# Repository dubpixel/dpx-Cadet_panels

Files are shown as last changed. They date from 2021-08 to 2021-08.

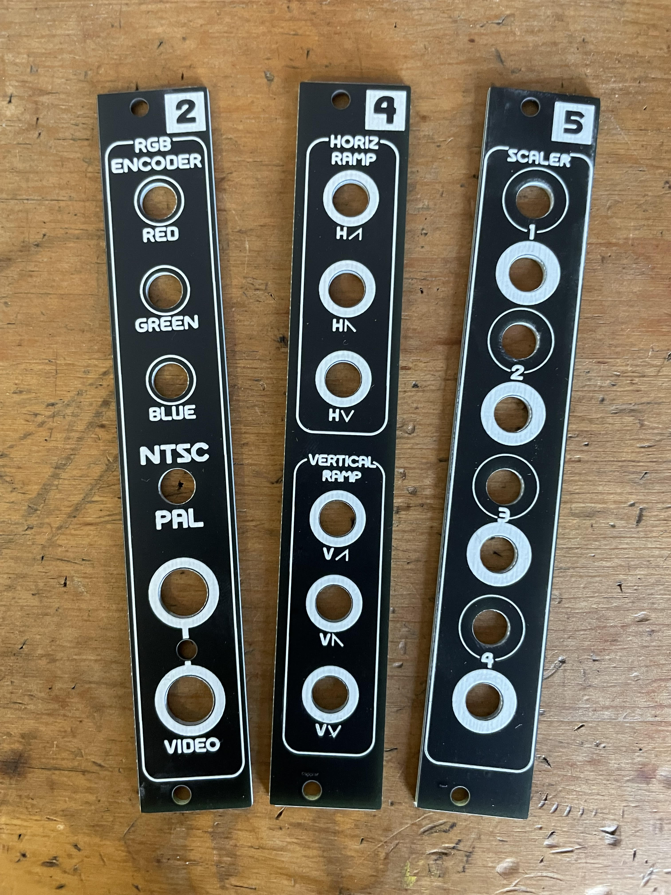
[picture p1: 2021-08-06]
photos/PANELS_1.jpg

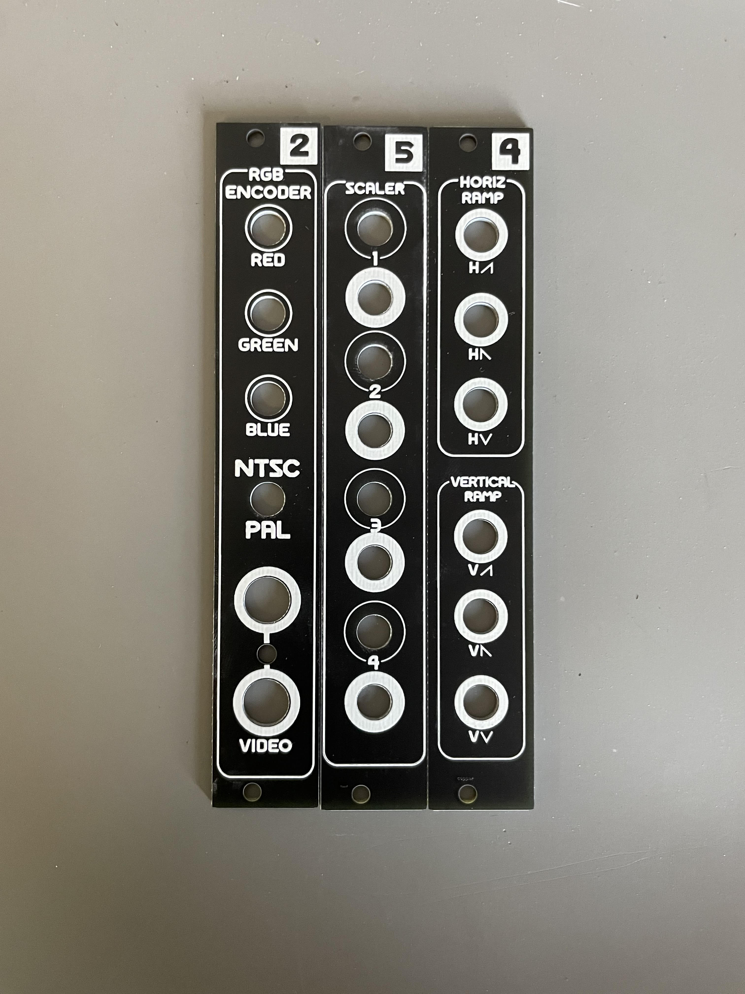
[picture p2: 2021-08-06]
photos/PANELS_5.jpg

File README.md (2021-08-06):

# dpx-Cadet_panels
**dubpixel** made panels for the LZX-cadet series of video synth modules.

most recently LZX cleared out their backstock of some old boards.
being in the middle of working on a euro-Vidiot panel, I used this as another exercise in panel making with a quicker time to live on checking if my process worked.

art-wise...
the style is trying to be a bit cadet-ish but im not the biggest fan of the art that i made - it was more about getting the holes right :)

there are here:
ai, dxf, fusion,360 eagle, and gerber files.
if you need some other intermediate perhaps i can provide. email below.

**//STATUS as of 8.4.21://**

- any place PJ302M is used I have used MJ-3536N as that is only part in stock i had to check spacing. 
- the diameter of the CUI part (MJ) is larger, and thusly the PJ302M fits with room to spare..maybe too much room (slop) but i only have 1 PJ to test with versus 12 MJ.

**CADET II  - RGB Encoder** :// looks very close -  if not 100% - did not have the lowermounting hardwarwe to confirm that it is in the right spot

**CADET IV - RAMPS** :// (revised) fits, looks good. I dont know why when i assembled before i didnt feel it was right. #needscoffee

**CADET V - SCALER** :// fits, looks good. might be an issue with the gerber in the silkscreen but also may be MFG. 

**//STATUS as of 8.2.21://**

**CADET II  - RGB Encoder** :// looks very close -  if not 100% - did not have the lowermounting hardwarwe to confirm that it is in the right spot

**CADET IV - RAMPS** :// NFG - needs bottom 3 holes to be adjusted. not sure what happened. PEBCAC (problem exists between caliper and chair)

**CADET V - SCALER** :// fits, looks good. might be an issue with the gerber in the silkscreen but also may be MFG. 

**if you arent up for mucking about and just wanna hit "PRINT" - **

go to gerbers-->fromFusion--> ...those are the files i printed formatted for JLCPCB, sorted accoding to status. made in fusion electronics (BLEGH!)

the files in fromEagle are theoretically identical from a physical perspective but may have minor variations in artwork as FE and eagle handle the dxf import in slightly different ways.
im not a fan of Autodesk ansclussing eagle into fusion.
but at least the poly import and text art workflow is getting speedier.

****process for creating these was roughly as follows****

==>draw 2d sketch in Fusion using parametric dimensions for edge spacing, board size, hole spacing etc.
- link all holes of same size to one hole.
- exit sketch, save, extrude 2mm
- create 3d PCB from sketch profile
- create fusion360 electronics project file.
- create a dummy schematic in that file
- create a 2d board link & it to the schemaitc
- link the 3d board to the 2d board

==>now you should have a board outline in fusion electronics on layer 20.  
- you can link this now to eagle if you want and continue the steps there, but the dxf import sadly works better in fusion electronics than eagle.
- plus also the polys move faster...renders cleaner. 
- RIP EAGLE... sad sad sad... George swears theyre not EOL'ing it but I dont beleive him. 
- so sorry if i say eagle anywhere and actually mean 'fusion electronics' blegghhh..

==>i now start work with the addhole.ulp
- use run 'addhole.ulp --install' to install the contextural menu
- then u can now click each hole outline and have it replace with the right drill hole. p neato
- back in fusion, now export your sketch to dxf
- import the DXF into AI onto a layer and lock it - this is your board outline and hole reference

==>now, make art in AI  on a new layer on top of the guide layer
- be sure to trace outlines of text, stroke with .1 mm line or smaller
- be sure to cut things with holes in them in half (like the letter O  - or even P...). knife/scissors tool
- add lots of points for paths  - not too many - but more points is better for maintaining curves once inside eagle. there is a balance between not choking eagle
- DELETE the guide lahyer (not turn off) - xcept for one point of registration... like a mounting screw hole
- export DXF in 2013 format. 

==>NOW - import into eagle or fusion electronics (actually imports less broken into fusion elec).
 - eagle is slower on the vector import and seems to want more points to not break P's o's and other 'cored' shapes/letters
 - newest version of fusion electronics also supports using any font for the 'text' object directly in FE/
 - FE files exported in eagle format and opened in eagle will break this new text format.
 - FE files exported in eagle format and opend in eagle will most likely not look the same or have some FUBAR ness to them
 - thusly I advise to do one path or the other, dont try to jump back and forth.
 - whichever u use - be sure to use THIS ULP here for DXF import.. use polygon mode not line.

- i import into tRef or something not used by normal things 
- usually needs an offset set on import to be off right.
- this is the (a?) trick... do not attempt to move the polys once imported. use the copy and paste command instead. delete old.. moves light years quicker
- get it all lined up - however u wanna try to do that...
- in the info-browser with the polys still selected,change the layer it exists on to whatever layer you want (copper, silk, stopmask etc)

==>dang i think youre about done now - or at least thats all the tricks/steps.
-export gerbs with your fab house settings of choice

i@dubpixel.tv if there are questions about this process.

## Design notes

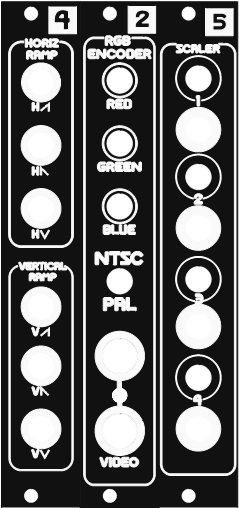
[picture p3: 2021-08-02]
gerber/fromFUSION/renders/PANELIZED_245 v4_2021-07-20_Combined_Top.png

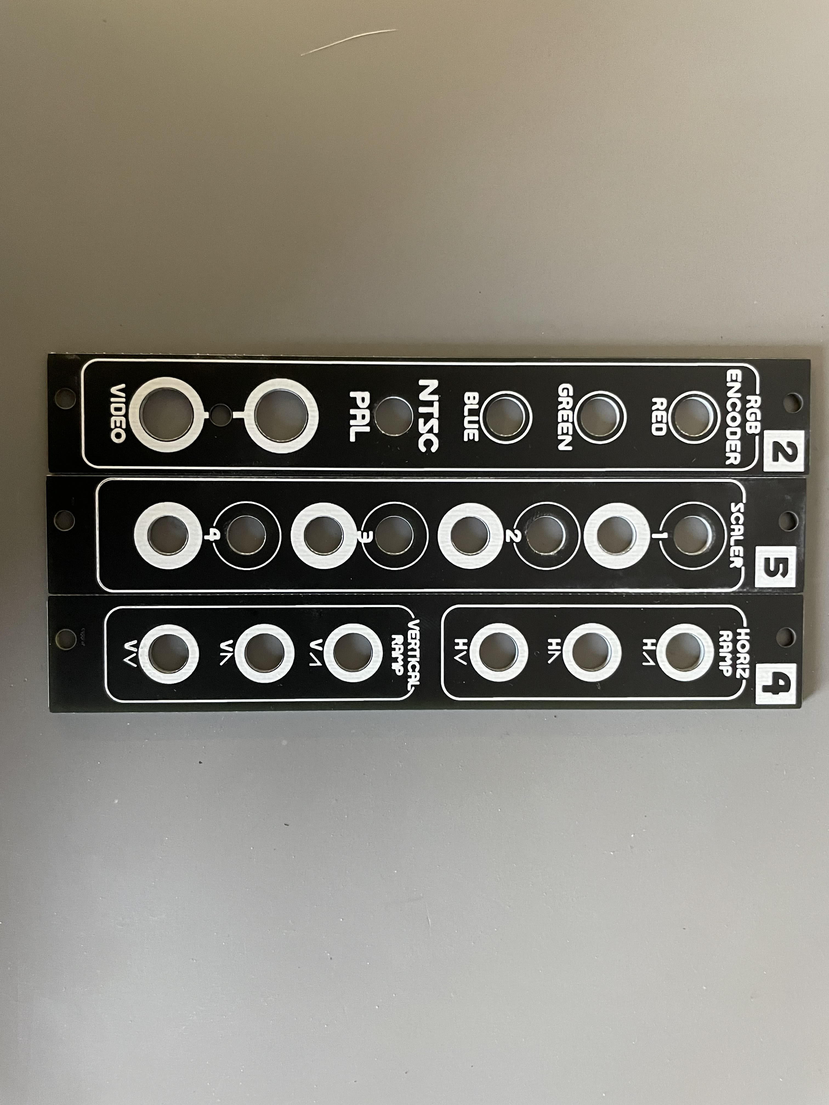
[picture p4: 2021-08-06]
photos/PANELS_4.jpg

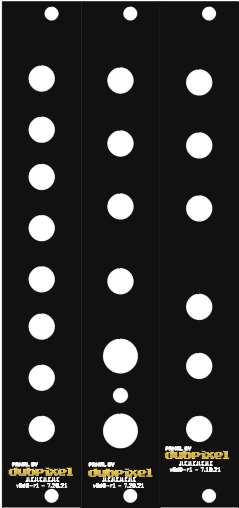
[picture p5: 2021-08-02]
gerber/fromFUSION/renders/PANELIZED_245 v4_2021-07-20_Combined_Bottom.png

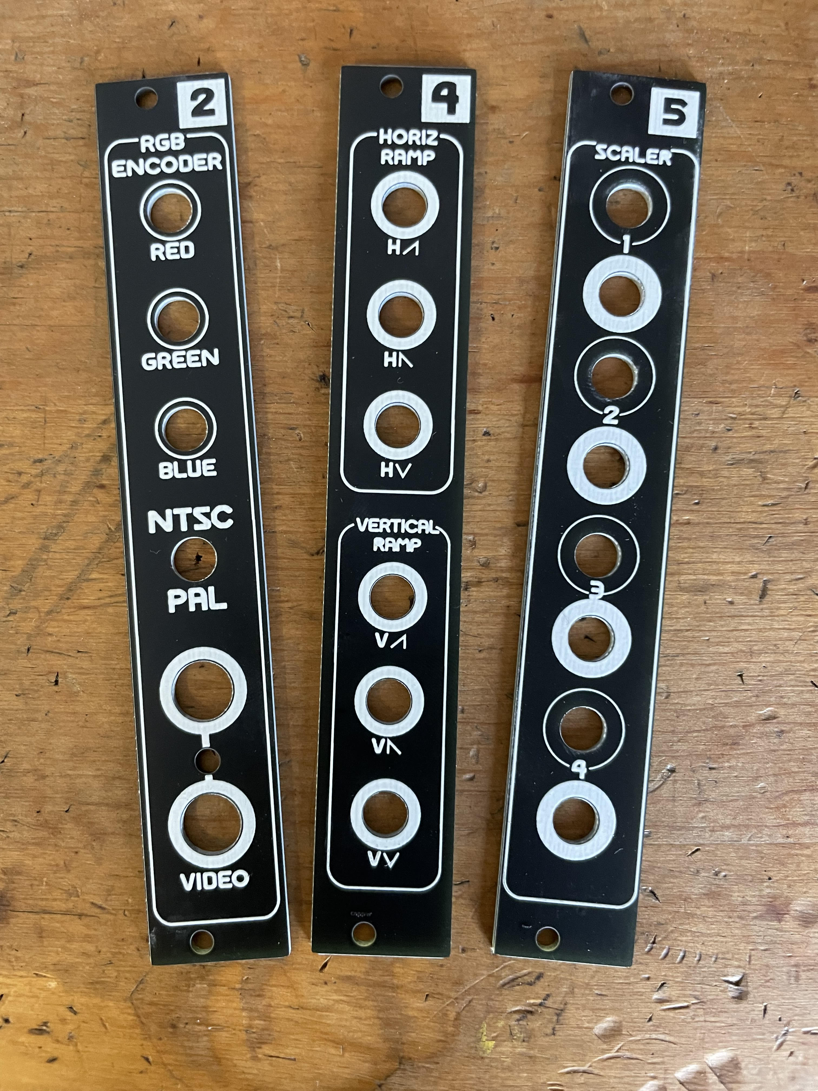
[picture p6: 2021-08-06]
photos/PANELS_2.jpg

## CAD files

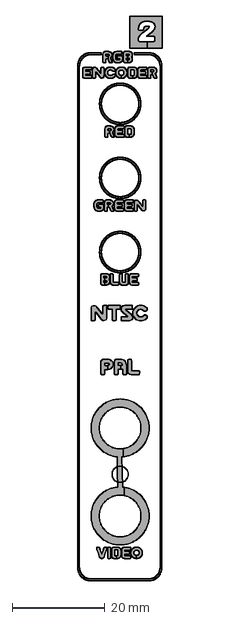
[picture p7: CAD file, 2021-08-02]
dxf_art/CADET-II-RGB_ENCODER_art7.dxf
18.3 x 121.9 mm

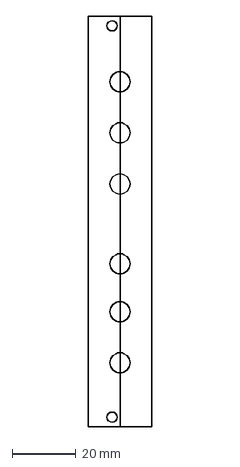
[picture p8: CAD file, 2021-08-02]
dxf_og/CADET-IV-RAMPS.dxf
20.0 x 128.5 mm

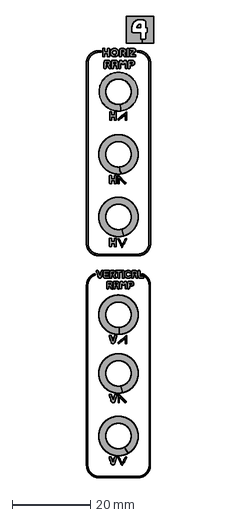
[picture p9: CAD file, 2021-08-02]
dxf_art/CADET-IV-RAMPS_art7.dxf
17.2 x 118.0 mm

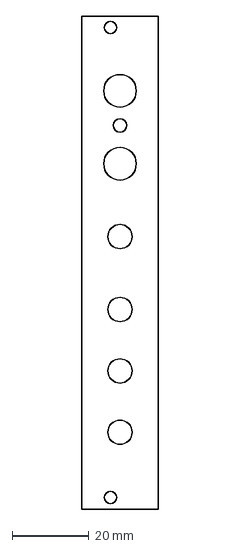
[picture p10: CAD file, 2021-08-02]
dxf_og/CADET-II-RGB_ENCODER.dxf
20.0 x 128.5 mm

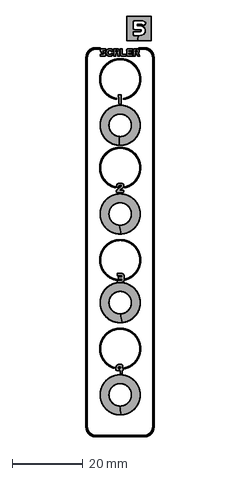
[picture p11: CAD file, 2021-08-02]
dxf_art/CADET-V-SCALER-ART.dxf
19.2 x 118.7 mm

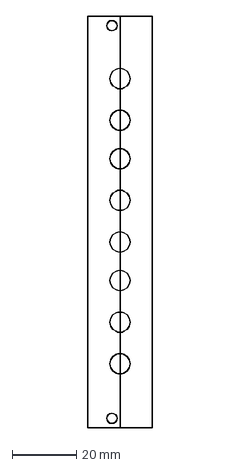
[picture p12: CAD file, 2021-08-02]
dxf_og/CADET-V-SCALER-V2.dxf
20.0 x 128.5 mm

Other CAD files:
f3d/FU-CADETII-RGBNCODER v6.f3d
f3d/FU-CADETIV-RAMPS v5.f3d
f3d/FU-CADETV-SCALER v5.f3d

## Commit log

2021-08-02 reorganize
    reorg & delete broken files
    [CADET-IV-RAMPS.dxf, CADET-IV-RAMPS_art65.dxf, CADET-IV-RAMPS_art7.dxf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]
2021-08-02 more reorg
    [CADET-II-RGB_ENCODER_artv5.dxf, CADET-V-SCALER.dxf, FU-CADETIV-RAMPS v5.f3d]
2021-08-02 more organizing
    woot
    [2D-CADETIV-RAMPS_v5_v7.brd, 2D-CADETIV-RAMPS_v5_v7_eagle.brd]
2021-08-04 derp derp
    i derp'd and thought that ramps was NFG. I tried it again. works pretty ok.
    [2D-CADETII-RGBNCODER_v6_v6.brd, 2D-CADETIV-RAMPS_v5_v7.brd, 2D-CADETIV-RAMPS_v5_v7_eagle.brd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]
